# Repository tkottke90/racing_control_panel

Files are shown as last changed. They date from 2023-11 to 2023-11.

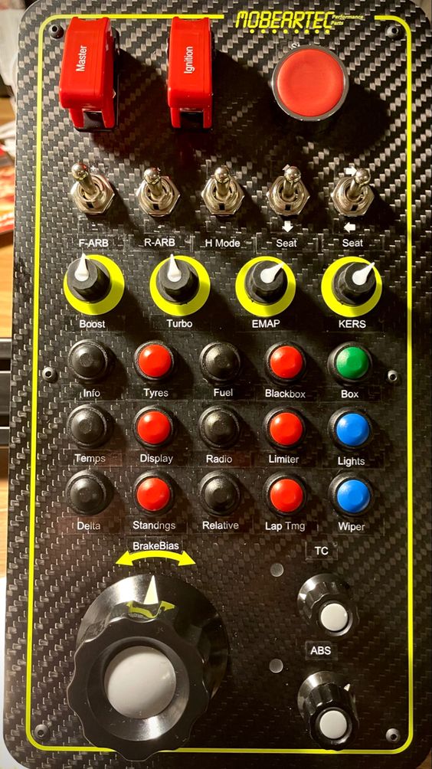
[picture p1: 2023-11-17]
Assets/d3e05cd24d6561cfe4274346a952a566.jpg

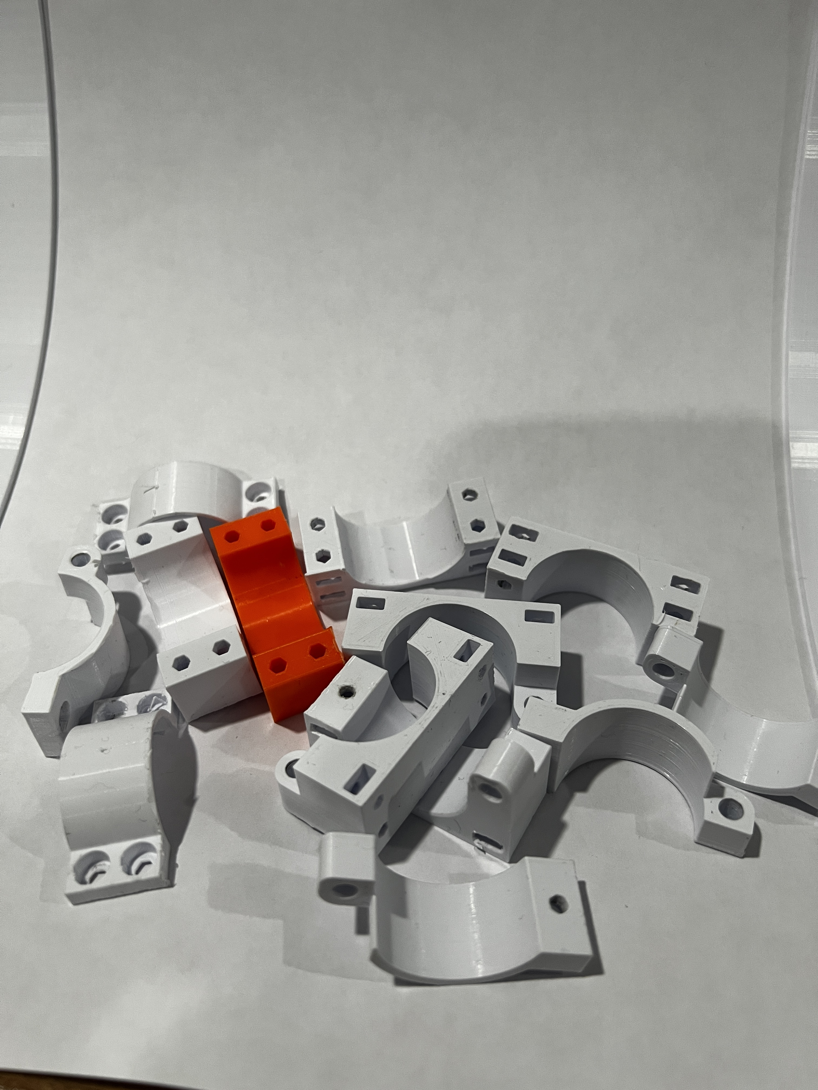
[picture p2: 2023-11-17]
Assets/hinge_itterations.JPG

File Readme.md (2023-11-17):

---
tags: 
updatedAt: 2023-08-04T14:02:19.869Z
updatedBy: md-metadata-parser
aliases:
  - Race Control Panel
---
# Project - Racing Control Panel

While using my sim racing rig I have struggled due to the limited number of keys on my steering wheel.  I think it would be a fun project to build a macro button panel that allowed me to add additional controls to enhance my experience.  

[Example](https://www.pinterest.com/pin/188517934393850154/)

Table of Contents
- [[#Requirements]]

---

# Requirements

1. I want an additional console I can add to my racing setup which will provide me with better control while playing iRacing
2. I want that console to include a slot that I can add my Elgato Stream Deck too
3. I want to be able to route the USB cable out of the back of the console
4. I would like additionally have  a controller with a large rotary encoder which I can make adjustments with
5. I want that rotary encoder to have a good volume of tight nearling
6. I want the rotary encoder to have a metalic finish
7. I want the console to be 3D printed
8. I want to be able to remove the console easily from the sim rig to avoid complicated cable management

---
## Resources

- [Great Scott Video: DIY or Buy Launchpad](https://www.youtube.com/watch?v=wyKStRyez5Y)
- [Tutorial: Arduino Joystick](https://www.youtube.com/watch?v=hoCOq9Ngp44)
- [Tutorial: FreeCAD Knurling](https://www.youtube.com/watch?v=UFnFFVXltN0)

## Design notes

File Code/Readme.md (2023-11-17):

---
tags: []
---
# Racing Control Panel Code

Table of Contents
- [[#References]]

---
## Working Notes

[2023-10-28] - I have been struggling with correctly connecting the rotary encoder to the Arduino.  My main concern is that there have been many "phantom" clicks and that has been causing issues when I view (or try to use it) as a joystick button pair because at random intervals I see the inverse direction button pressed when I turn the encoder.

Example Serial Output:
```
Dir: CW
Dir: CW
Dir: CCW
Dir: CW
Dir: CCW
Dir: CW
```

This had me perplexed as even with a hardware debouncer and software debouncing I could not seem to get the inputs to be clean and clear.  In one of my recent experiments I did come across a discovery that my encoder.  I have documented all of this in my [[Rotary Encoders#Usage Experience Notes|Rotary Encode Usage Notes]]

---
## References
- [Video: How to use a Rotary Encoder with an Arduino - CODE EXPLAINED!](https://youtu.be/fgOfSHTYeio?si=N0kpVSW-hEnzY00c)

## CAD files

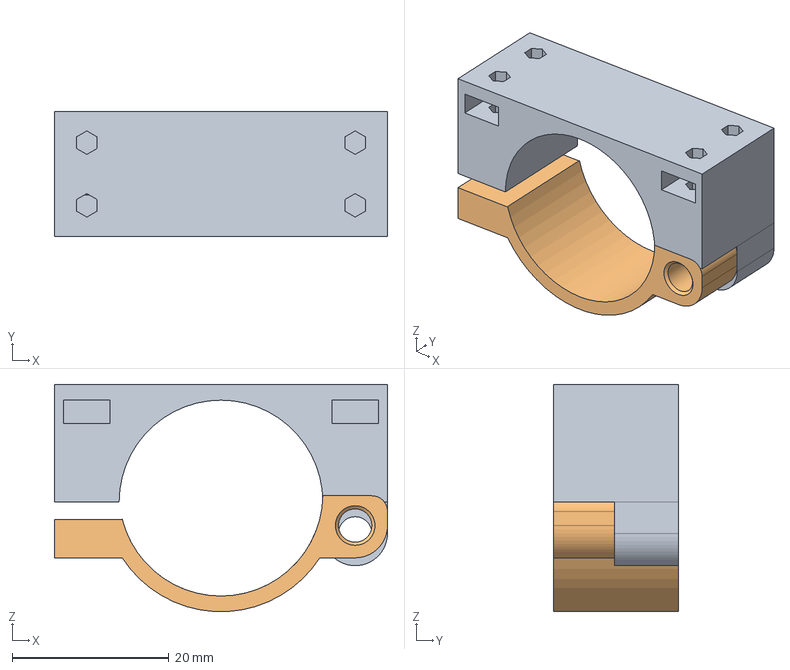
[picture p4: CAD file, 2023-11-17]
Part Concept.FCStd
42.5 x 16.0 x 29.0 mm
Clamp Top v2
Clamp Bottom v2

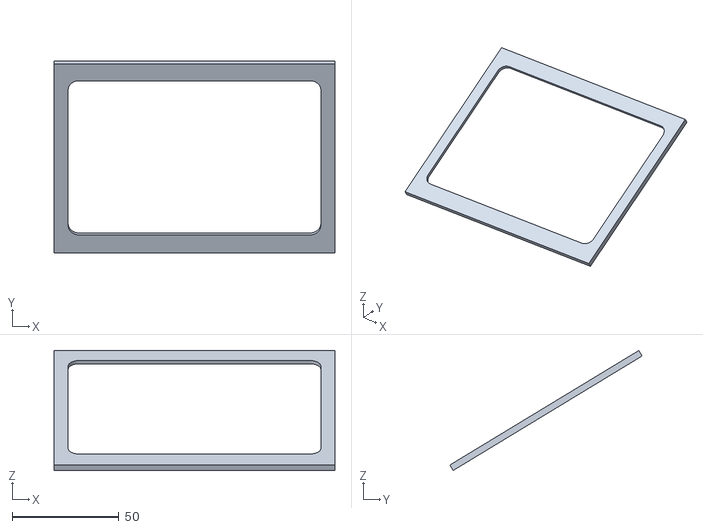
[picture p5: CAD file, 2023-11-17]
STL/Part Concept-StreamDeck Panel-Top.rev-02.stl
131.5 x 90.0 x 56.2

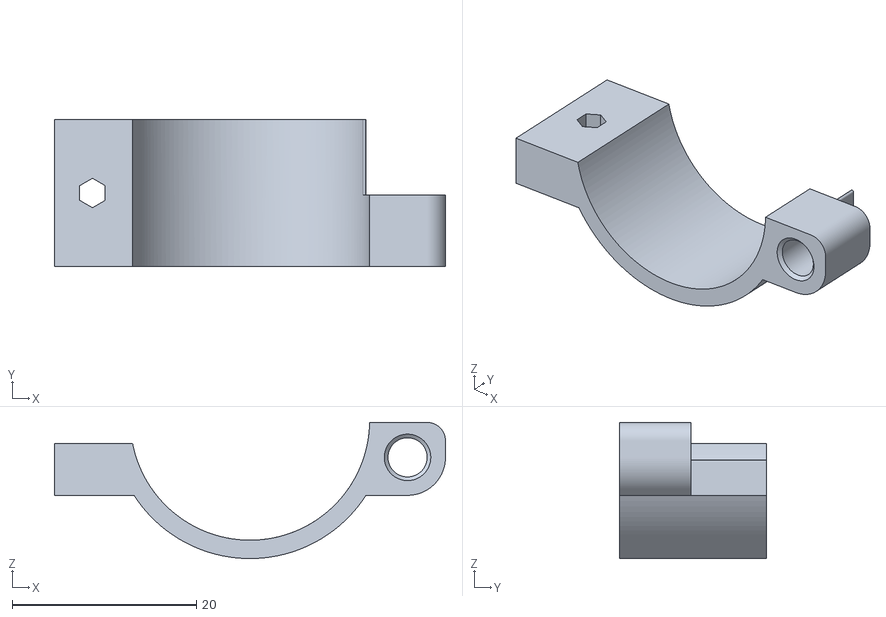
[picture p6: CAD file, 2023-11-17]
STL/Part Concept-ClampBottomv2.rev-03.stl
42.5 x 16.0 x 14.8

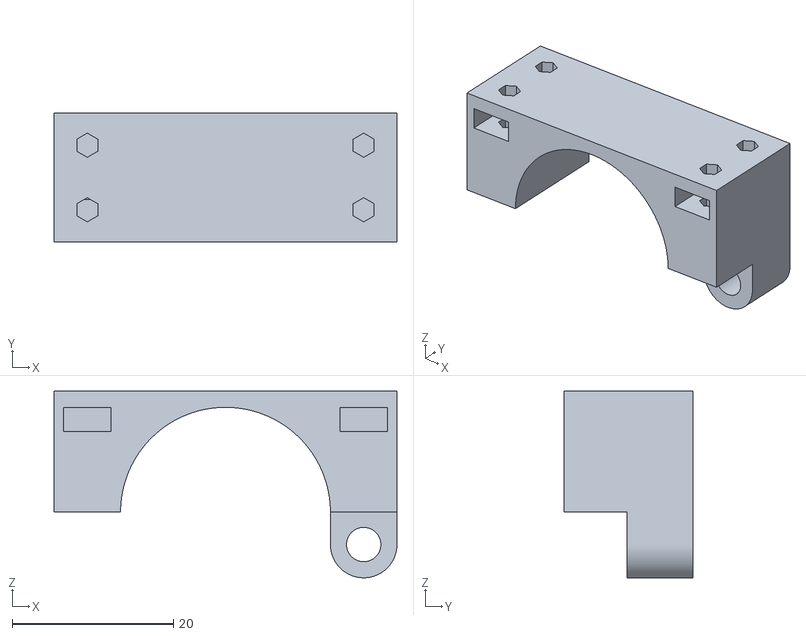
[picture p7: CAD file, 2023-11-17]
STL/Part Concept-ClampTopv2.rev-03.stl
42.5 x 16.0 x 23.1

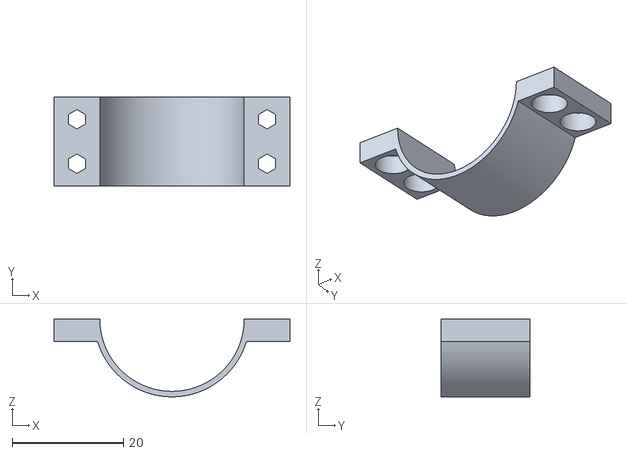
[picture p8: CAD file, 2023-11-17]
STL/Part Concept-Body001.rev-02.stl
42.5 x 16.0 x 14.0

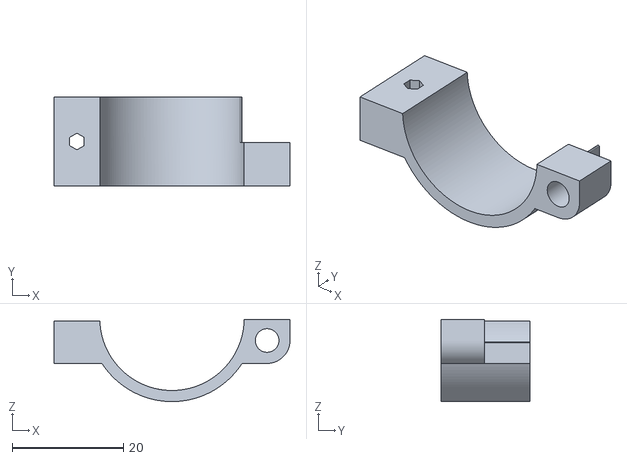
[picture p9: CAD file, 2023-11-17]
STL/Part Concept-BottomClampv2.rev-01.stl
42.5 x 16.0 x 14.8

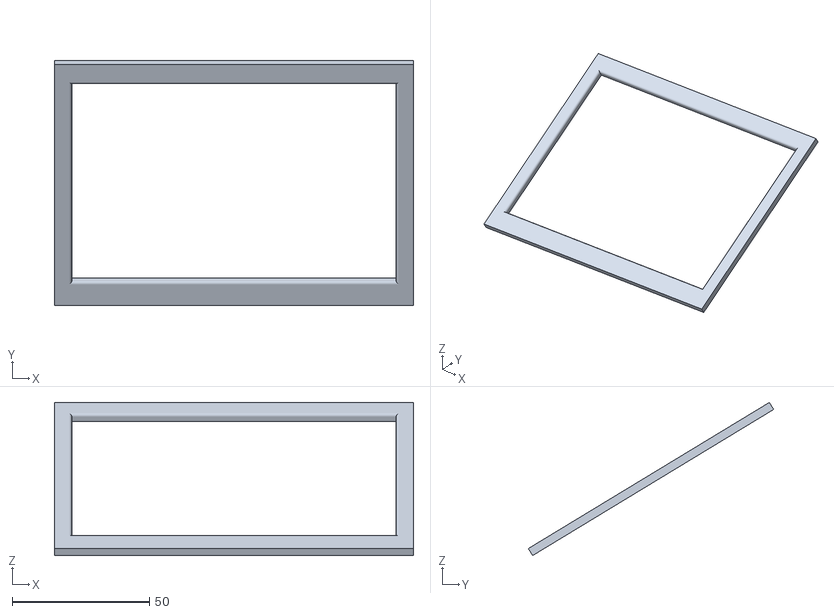
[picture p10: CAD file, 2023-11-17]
STL/Part Concept-StreamDeck Panel.rev-01.stl
130.9 x 89.5 x 55.8

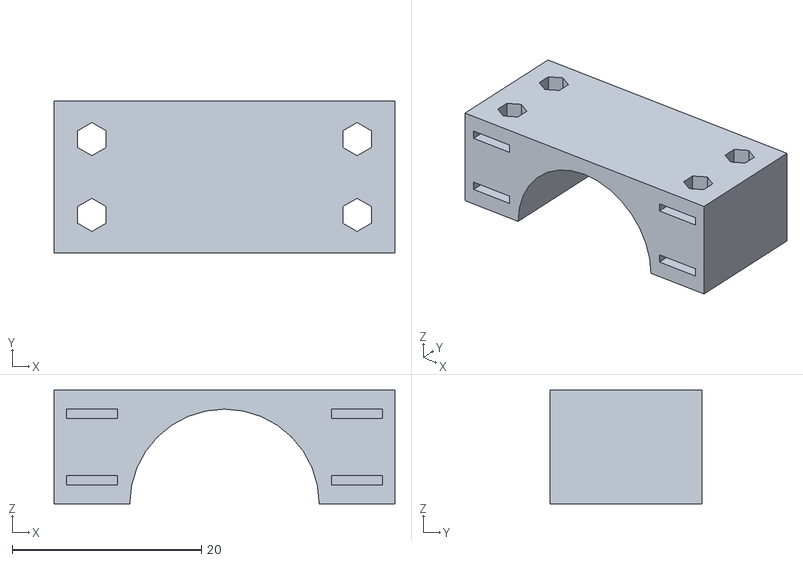
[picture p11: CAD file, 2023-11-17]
STL/Part Concept-Body.stl
36.0 x 16.0 x 12.0

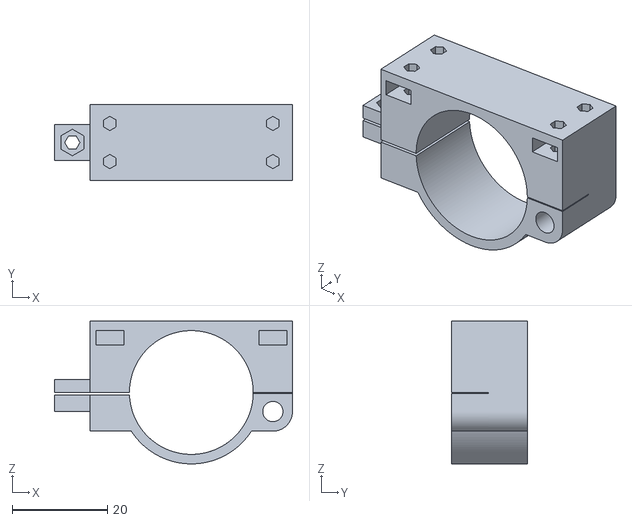
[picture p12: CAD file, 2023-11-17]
STL/Part Concept-Clamp.rev-03.stl
50.0 x 16.0 x 30.0

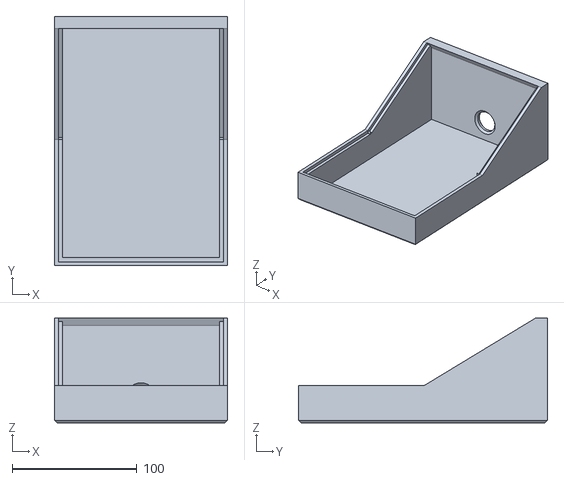
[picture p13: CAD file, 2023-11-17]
STL/Part Concept-Console.rev-02.stl
138.7 x 200.0 x 83.8

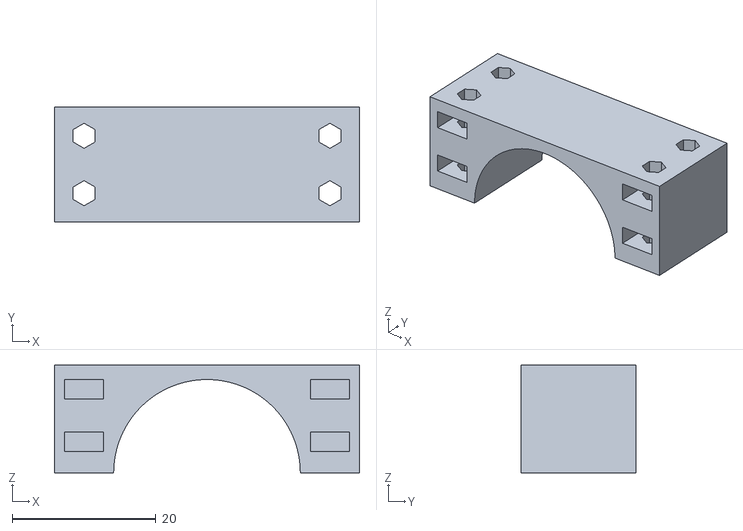
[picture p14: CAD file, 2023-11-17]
STL/Part Concept-Body.rev-02.stl
42.5 x 16.0 x 15.0

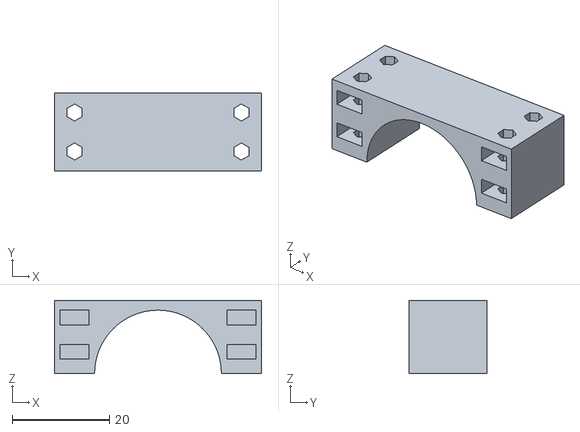
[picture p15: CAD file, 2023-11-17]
STL/Part Concept-Clamp-Top.rev-03.stl
42.5 x 16.0 x 15.0

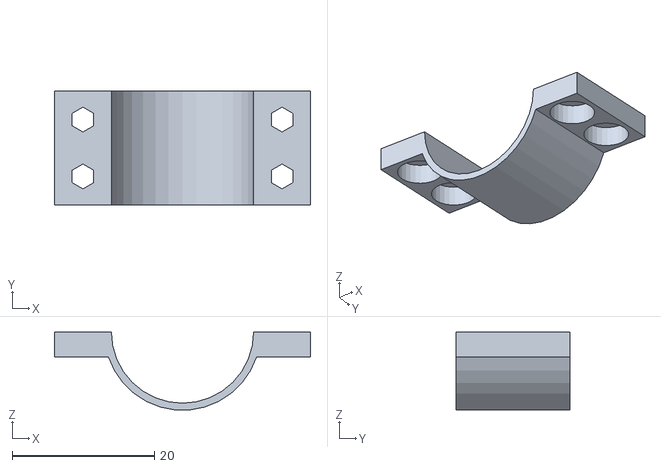
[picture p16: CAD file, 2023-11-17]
STL/Part Concept-Body001.stl
36.0 x 16.0 x 10.9

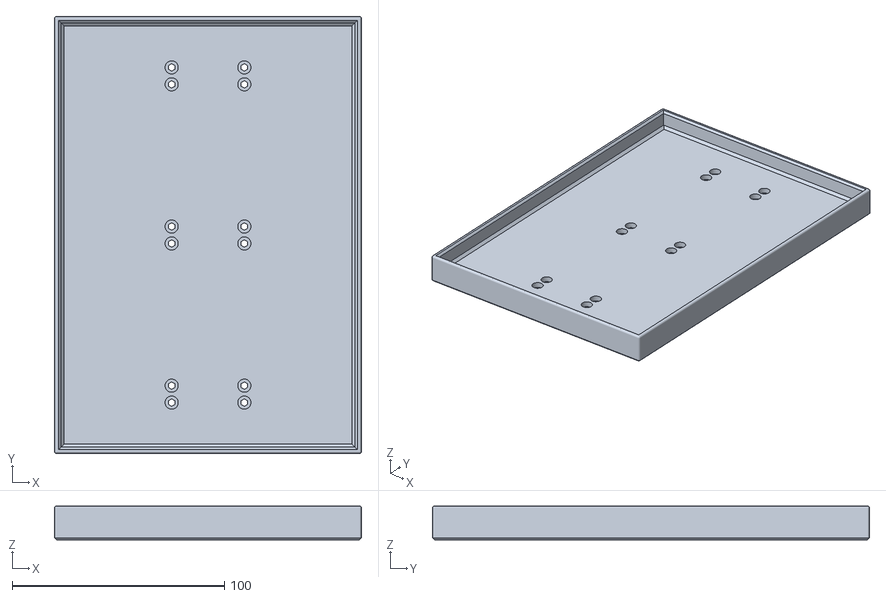
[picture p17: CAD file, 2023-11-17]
STL/Part Concept-Rig Mount.rev-01.stl
144.7 x 206.0 x 16.0

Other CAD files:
STL/Part Concept-TopClampv2.rev-01.stl
STL/Part Concept-ClampBottomv2.rev-04-1.stl
STL/Part Concept-ClampBottomv2.rev-04-2.stl
STL/Part Concept-StreamDeck Panel Bottom.stl
STL/Part Concept-ClampBottomv2.rev-02.stl
STL/Part Concept-ClampTopv2.rev-02.stl
STL/Part Concept-Console.rev-01.stl
STL/StreamDeck_Cover.stl

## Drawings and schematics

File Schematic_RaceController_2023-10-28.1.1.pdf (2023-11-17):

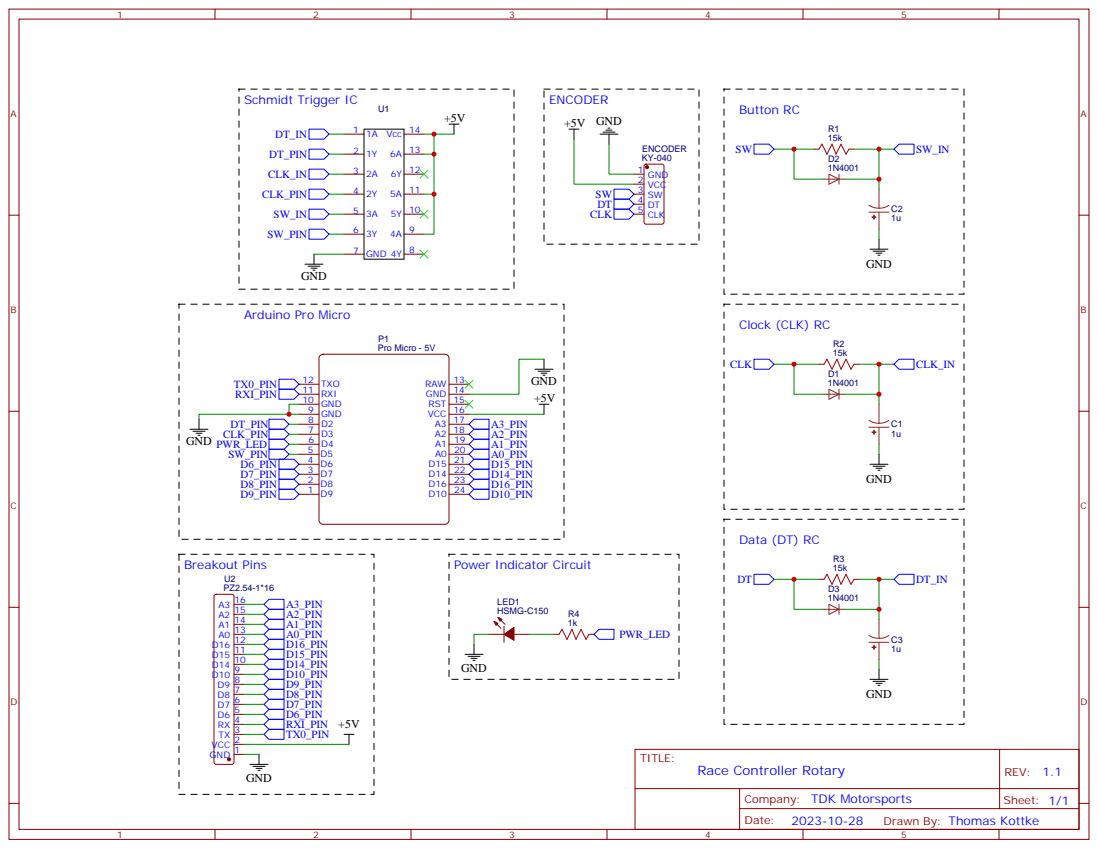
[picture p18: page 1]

Drawn By: Thomas Kottke

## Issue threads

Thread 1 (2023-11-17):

Design Encoder Mounting Panel

tkottke90, 2023-11-17:
**As a** control panel user
**I would like** the rotary encoder to be mounted to the housing
**So that I** can use the rotary use the rotary encoder to make adjustments while racing

Acceptance Criteria

- A prototype panel has been created that supports the Rotary Encoder and the supporting circuit board

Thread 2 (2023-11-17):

Design a nob for the rotery encoder

tkottke90, 2023-11-17:
**As a** control panel user
**I would like** the rotary encoder to have a reasonable sized knob for easy access
**So that I** can reliably make adjustments during a race

### Acceptance Criteria

- A prototype knob has been created fits the rotary encoder shaft

### Notes

- I think a good amount of knurling would be a good idea to ensure there are many opportunities for a good grip

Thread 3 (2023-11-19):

Troubleshoot SW Button not working

tkottke90, 2023-11-19:
# Description

I went ahead and wired up one of my boards with components.  I found that the rotary buttons work great and I am able to see the change on my PC.  However whenever depress the shaft, I am not getting the button click event triggering.  I am not sure if this is a hardware or software thing

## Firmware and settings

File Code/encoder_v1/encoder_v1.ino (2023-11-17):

#include <Joystick.h>

const Joystick_ Joystick;

// Indicators
const uint8_t pwr_led = 5;

// Rotary Inputs
const uint8_t sw = 5;
const uint8_t clk = 3;
const uint8_t dt = 2;

// Joystick Outputs
const uint8_t js_sw = 0;
const uint8_t js_ccw = 1;
const uint8_t js_cw = 2;

// Button State
int lastButtonState = 0;

// Rotary State
volatile long count = 0;
long lastCountVal = 0;

void encoder_isr()
{
  // Serial.println("ISR");
  // Table contains 16 positions which we can align with the first 4 bits
  // of our old_value variable.
  //
  // Ex:
  //  old_val = 0010 0010 (Binary 34)
  //
  //  > We get the important bits by adding a 0000 1111 value
  //  important_bits = old_val & 0b1111
  //
  //       0010 0010
  //     & 0000 1111
  //     -----------
  //       0000 0010 (Binary 3)
  //
  //  We can then use this to look up the next value in the lookup_table
  //
  static const int8_t lookup_table[] = {0, -1, 1, 0, 1, 0, 0, -1, -1, 0, 0, 1, 0, 1, -1, 0};
  static const uint8_t rotaryIntervalsPerDetent = 2;
  static int enc_val = 0;
  static int8_t old_val = 3;

  // Shift Previous State
  // Ex: 0000 0010 => 0000 1000
  old_val <<= 2;

  // If CLK is high, then add a 1 to the 2 pos in the old_val binary
  if (digitalRead(clk))
    old_val |= 0b0010;

  // If DT is high, then add a 1 to the 2 pos in the old_val binary
  if (digitalRead(dt))
    old_val |= 0b0001;

  // Use the first 4 bits of the old_val value to get a
  enc_val += lookup_table[(old_val & 0b1111)];
  
  // We want to align our events with the encoder we are using.  Some
  // have 4 state changes per "detent" and some have 2.  To manage this
  // we store the intervals per detent in a variable
  if (enc_val > 1)
  {
    long changeValue = 1;

    count = count + changeValue;
    enc_val = 0;
  }

  // We need to invert the math for counter-clockwise
  if (enc_val < -1)
  {
    long changeValue = -1;

    count = count + changeValue;
    enc_val = 0;
  }
}

void temp() {
  Serial.println("Temp");
}

void setup()
{
  pinMode(sw, INPUT_PULLUP);
  pinMode(clk, INPUT_PULLUP);
  pinMode(dt, INPUT_PULLUP);
  pinMode(pwr_led, OUTPUT);

  digitalWrite(pwr_led, HIGH);

  attachInterrupt(digitalPinToInterrupt(clk), encoder_isr, CHANGE);
  attachInterrupt(digitalPinToInterrupt(dt), encoder_isr, CHANGE);

  lastButtonState = digitalRead(sw);

  Joystick.begin();
  Serial.begin(9600);
  // Need to wait for the Serial module to boot before we can use it in the setup
  while (!Serial) ;

  Serial.println("Script Starting");
}

void loop()
{
  // delay(20);
  // Read Button Value
  lastButtonState = checkPinState(sw, lastButtonState, js_sw);

  // Check if the encoder state has changed
  if (count != lastCountVal)
  { 
    // Trigger the joystick buttons based on the direction of the counter
    if (count > lastCountVal)
    {
      // Clockwise
      Joystick.setButton(js_cw, HIGH);
      delay(40);
      Joystick.setButton(js_cw, LOW);
    }
    else
    {
      Joystick.setButton(js_ccw, HIGH);
      delay(40);
      Joystick.setButton(js_ccw, LOW);
    }

    lastCountVal = count;
    
  }
}

int checkPinState(uint8_t pin, int prev, uint8_t jsOut)
{
  int val = digitalRead(pin);

  if (val != prev)
  {
    Joystick.setButton(jsOut, val);
  }

  return val;
}
